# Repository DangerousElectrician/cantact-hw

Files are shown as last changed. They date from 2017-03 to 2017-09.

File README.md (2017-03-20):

I need a sensor node that sits on a CAN bus. This looks like a good place to start.

# CANtact Hardware

This repository contains the hardware design files for the CANtact tool. They 
can be opened and edited with [KiCad](http://www.kicad-pcb.org/).

A PDF of the schematic is available
[here](https://github.com/CANtact/cantact-hw/blob/master/cantact.pdf?raw=true).

## License

Hardware files released under the [Creative Commons Attribution-ShareAlike 4.0
International License](http://creativecommons.org/licenses/by-sa/4.0/) (CC BY-SA
4.0)

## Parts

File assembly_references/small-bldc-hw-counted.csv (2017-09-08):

Reference | Value | Footprint | Datasheet | MPN | MPN | count
R25 | 100 | Resistors_SMD:R_0201 |  | AC0201JR-07100RL
R26 | 100 | Resistors_SMD:R_0201 |  | AC0201JR-07100RL
R32 | 100 | Resistors_SMD:R_0201 |  | AC0201JR-07100RL
R33 | 100 | Resistors_SMD:R_0201 |  | AC0201JR-07100RL | AC0201JR-07100RL | 4
U2 | AZ1117C | TO_SOT_Packages_SMD:SOT89-3_Housing |  | AZ1117CR-3.3TRG1 | AZ1117CR-3.3TRG1 | 1
Q1 | BUK7K13-60E | hlib:SOT-1205 |  | BUK7K13-60EX
Q2 | BUK7K13-60E | hlib:SOT-1205 |  | BUK7K13-60EX
Q3 | BUK7K13-60E | hlib:SOT-1205 |  | BUK7K13-60EX | BUK7K13-60EX | 3
C20 | 22n | Capacitors_SMD:C_0603 |  | C0603C223K1RACTU | C0603C223K1RACTU | 1
C21 | 10u | Capacitors_SMD:C_0805 |  | C0805C106K8PACTU | C0805C106K8PACTU | 1
C22 | 2.2u | Capacitors_SMD:C_0603 |  | CC0603MRX5R7BB225 | CC0603MRX5R7BB225 | 1
C2 | 0.1u | Capacitors_SMD:C_0402 |  | CL05A104KP5NNNC
C9 | 0.1u | Capacitors_SMD:C_0402 |  | CL05A104KP5NNNC | CL05A104KP5NNNC | 2
C12 | 0.1u | Capacitors_SMD:C_0402 |  | CL05B104KO5NNNC
C14 | 0.1u | Capacitors_SMD:C_0402 |  | CL05B104KO5NNNC
C36 | 0.1u | Capacitors_SMD:C_0402 |  | CL05B104KO5NNNC
C37 | 0.1u | Capacitors_SMD:C_0402 |  | CL05B104KO5NNNC | CL05B104KO5NNNC | 4
C4 | 4.7u | Capacitors_SMD:C_0603 |  | CL10B475KQ8NQNC | CL10B475KQ8NQNC | 1
C23 | 22u | Capacitors_SMD:C_0805 |  | CL21A226MQQNNNE | CL21A226MQQNNNE | 1
C18 | 4.7u | Capacitors_SMD:C_0805 |  | CL21A475KAQNNNG | CL21A475KAQNNNG | 1
C24 | 0.1u | Capacitors_SMD:C_0805 |  | CL21B104KCFNNNE
C29 | 0.1u | Capacitors_SMD:C_0805 |  | CL21B104KCFNNNE | CL21B104KCFNNNE | 2
R27 | 1m | hlib:R_shunt_4_terminal_2512 |  | CRE2512-FZ-R001E-3
R34 | 1m | hlib:R_shunt_4_terminal_2512 |  | CRE2512-FZ-R001E-3 | CRE2512-FZ-R001E-3 | 2
U3 | DRV8301 | crf1:TSSOP-56-PP |  | DRV8301DCAR | DRV8301DCAR | 1
R18 | 15k | Resistors_SMD:R_0201 |  | ERJ-1GEJ153C | ERJ-1GEJ153C | 1
R16 | 18k | Resistors_SMD:R_0201 |  | ERJ-1GEJ183C | ERJ-1GEJ183C | 1
Y1 | 16MHz | hlib:Crystal_SMD_3225-4pin_3.2x2.5mm |  | FA-238 16.0000MB-K3 | FA-238 16.0000MB-K3 | 1
C1 | 10p | Capacitors_SMD:C_0201 |  | GRM0335C1H100JA01D
C5 | 10p | Capacitors_SMD:C_0201 |  | GRM0335C1H100JA01D | GRM0335C1H100JA01D | 2
C19 | 120p | Capacitors_SMD:C_0201 |  | GRM0335C1H121JA01D | GRM0335C1H121JA01D | 1
C32 | 2.2n | Capacitors_SMD:C_0201 |  | GRM033R71A222KA01D
C33 | 2.2n | Capacitors_SMD:C_0201 |  | GRM033R71A222KA01D
C34 | 2.2n | Capacitors_SMD:C_0201 |  | GRM033R71A222KA01D
C35 | 2.2n | Capacitors_SMD:C_0201 |  | GRM033R71A222KA01D | GRM033R71A222KA01D | 4
C15 | 4.7n | Capacitors_SMD:C_0201 |  | GRM033R71A472KA01D | GRM033R71A472KA01D | 1
C17 | 6.8n | Capacitors_SMD:C_0201 |  | GRM033R71A682KA01D | GRM033R71A682KA01D | 1
C11 | 1u | Capacitors_SMD:C_0402 |  | GRM155R61A105KE15D | GRM155R61A105KE15D | 1
C16 | 2.2u | Capacitors_SMD:C_0402 |  | GRM155R61A225KE95D | GRM155R61A225KE95D | 1
C26 | 0.1u | Capacitors_SMD:C_0402 |  | GRM155R61E104KA87D
C27 | 0.1u | Capacitors_SMD:C_0402 |  | GRM155R61E104KA87D
C28 | 0.1u | Capacitors_SMD:C_0402 |  | GRM155R61E104KA87D | GRM155R61E104KA87D | 3
C13 | 4.7u | Capacitors_SMD:C_0603 |  | GRM188R60J475KE19D
C8 | 4.7u | Capacitors_SMD:C_0603 |  | GRM188R60J475KE19D | GRM188R60J475KE19D | 2
C3 | 0.1u | Capacitors_SMD:C_0402 |  | GRM188R71C104KA01D
C6 | 0.1u | Capacitors_SMD:C_0402 |  | GRM188R71C104KA01D
C7 | 0.1u | Capacitors_SMD:C_0402 |  | GRM188R71C104KA01D | GRM188R71C104KA01D | 3
C10 | 10n | Capacitors_SMD:C_0402 |  | GRM188R71H103KA01D | GRM188R71H103KA01D | 1
C31 | 100u | Capacitors_SMD:C_1206 |  | GRM31CR60J107ME39L | GRM31CR60J107ME39L | 1
C25 | 4.7u | Capacitors_SMD:C_1210 |  | HMK325C7475KN-TE
C30 | 4.7u | Capacitors_SMD:C_1210 |  | HMK325C7475KN-TE
C38 | 4.7u | Capacitors_SMD:C_1210 |  | HMK325C7475KN-TE | HMK325C7475KN-TE | 3
D1 | LED-GREEN | LEDs:LED_0603 |  | LTST-C191KGKT | LTST-C191KGKT | 1
D2 | LED-RED | LEDs:LED_0603 |  | LTST-C191KRKT | LTST-C191KRKT | 1
U4 | MCP2562-E/SN | Housings_SOIC:SOIC-8_3.9x4.9mm_Pitch1.27mm |  | MCP2562FD-H/SN | MCP2562FD-H/SN | 1
R4 | 120 | Resistors_SMD:R_0201 |  | MCR03ERTF1200
R5 | 1k | Resistors_SMD:R_0201 |  | MCR03ERTF1200
R6 | 1k | Resistors_SMD:R_0201 |  | MCR03ERTF1200 | MCR03ERTF1200 | 3
R3 | 100k | Resistors_SMD:R_0201 |  | MCR03ERTF5100 | MCR03ERTF5100 | 1
JP1 | Boot Mode | Resistors_SMD:R_0603_HandSoldering |  | n/a
J3 | CONN_01X01 | hlib:SolderWirePad_single_SMD_5x3.5mm_holes |  | n/a
J4 | CONN_01X01 | hlib:SolderWirePad_single_SMD_5x3.5mm_holes |  | n/a
J5 | CONN_01X01 | hlib:SolderWirePad_single_SMD_5x3.5mm_holes |  | n/a
J8 | CONN_01X01 | hlib:SolderWirePad_single_SMD_5x3.5mm_holes |  | n/a
J9 | CONN_01X01 | hlib:SolderWirePad_single_SMD_5x3.5mm_holes |  | n/a
JP3 | Jumper_NC_Small | Resistors_SMD:R_0402 |  | n/a
JP2 | Jumper_NO_Small | Resistors_SMD:R_0402 |  | n/a
JP4 | Tie | hlib:NetTie-I_Connected_SMD |  | n/a | n/a
L1 | 22u | Inductors:Inductor_Taiyo-Yuden_NR-60xx |  | NR6045T220M | NR6045T220M | 1
D3 | D_Schottky | Diodes_SMD:D_SOD-123F |  | NRVTS260ESFT1G | NRVTS260ESFT1G | 1
R19 | 10k | Resistors_SMD:R_0201 |  | RC0201JR-0710KL
R20 | 10k | Resistors_SMD:R_0201 |  | RC0201JR-0710KL
R21 | 10k | Resistors_SMD:R_0201 |  | RC0201JR-0710KL
R9 | 10k | Resistors_SMD:R_0201 |  | RC0201JR-0710KL | RC0201JR-0710KL | 4
R22 | 220k | Resistors_SMD:R_0201 |  | RC0201JR-07220KL | RC0201JR-07220KL | 1
R7 | 2k | Resistors_SMD:R_0402 |  | RC0402JR-072KL
R8 | 2k | Resistors_SMD:R_0402 |  | RC0402JR-072KL | RC0402JR-072KL | 2
R23 | 2R2 | Resistors_SMD:R_0402 |  | RC0402JR-072R2L
R24 | 2R2 | Resistors_SMD:R_0402 |  | RC0402JR-072R2L
R28 | 2R2 | Resistors_SMD:R_0402 |  | RC0402JR-072R2L
R29 | 2R2 | Resistors_SMD:R_0402 |  | RC0402JR-072R2L
R30 | 2R2 | Resistors_SMD:R_0402 |  | RC0402JR-072R2L
R31 | 2R2 | Resistors_SMD:R_0402 |  | RC0402JR-072R2L | RC0402JR-072R2L | 6
R13 | 2k7 | Resistors_SMD:R_0201 |  | RC0603F272CS
R14 | 2k7 | Resistors_SMD:R_0201 |  | RC0603F272CS
R15 | 2k7 | Resistors_SMD:R_0201 |  | RC0603F272CS
R2 | 2k7 | Resistors_SMD:R_0201 |  | RC0603F272CS | RC0603F272CS | 4
R17 | 3k3 | Resistors_SMD:R_0201 |  | RC0603F332CS | RC0603F332CS | 1
R1 | 47k | Resistors_SMD:R_0603 |  | RC0603JR-074K7L
R10 | 47k | Resistors_SMD:R_0603 |  | RC0603JR-074K7L
R11 | 47k | Resistors_SMD:R_0603 |  | RC0603JR-074K7L
R12 | 47k | Resistors_SMD:R_0603 |  | RC0603JR-074K7L | RC0603JR-074K7L | 4
J2 | TEMP | Connectors_JST:JST_SH_SM02B-SRSS-TB_02x1.00mm_Angled |  | SM02B-SRSS-TB(LF)(SN) | SM02B-SRSS-TB(LF)(SN) | 1
J6 | CAN | Connectors_JST:JST_SH_SM04B-SRSS-TB_04x1.00mm_Angled |  | SM04B-SRSS-TB(LF)(SN)
J7 | I2C | Connectors_JST:JST_SH_SM04B-SRSS-TB_04x1.00mm_Angled |  | SM04B-SRSS-TB(LF)(SN) | SM04B-SRSS-TB(LF)(SN) | 2
P2 | SWD | Connectors_JST:JST_SH_SM05B-SRSS-TB_05x1.00mm_Angled |  | SM05B-SRSS-TB(LF)(SN) | SM05B-SRSS-TB(LF)(SN) | 1
J1 | More IO | Connectors_JST:JST_SH_SM12B-SRSS-TB_12x1.00mm_Angled |  | SM12B-SRSS-TB(LF)(SN) | SM12B-SRSS-TB(LF)(SN) | 1
U1 | STM32F042C6T6 | Housings_QFP:LQFP-48_7x7mm_Pitch0.5mm |  | STM32F042C6T6 | STM32F042C6T6 | 1

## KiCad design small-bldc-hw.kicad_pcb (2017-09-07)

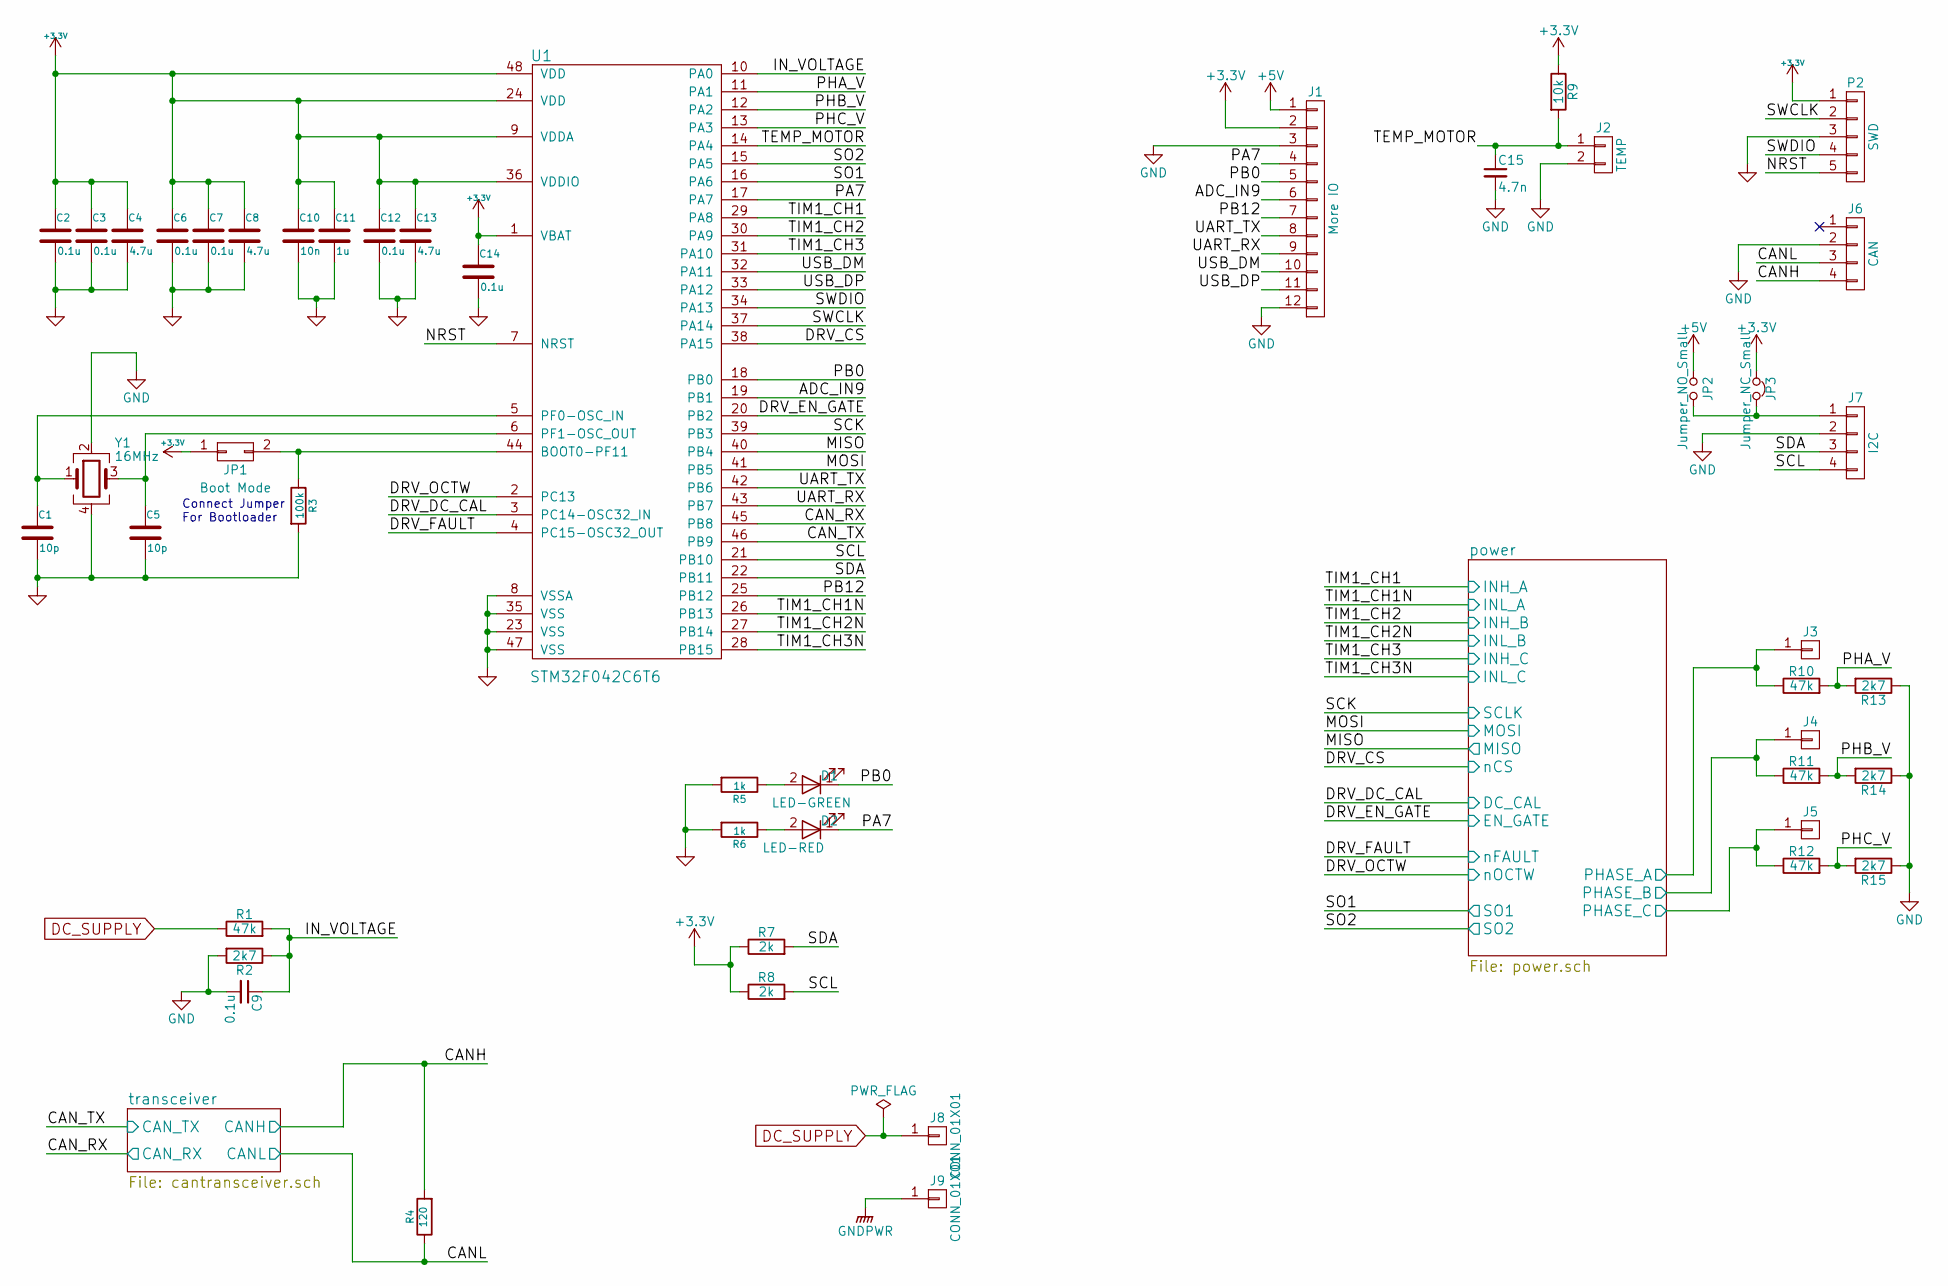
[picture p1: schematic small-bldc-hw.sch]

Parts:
C1, C5: 10p; C_0201; MPN GRM0335C1H100JA01D
C2, C9: 0.1u; C_0402; MPN CL05A104KP5NNNC
C3, C6, C7: 0.1u; C_0402; MPN GRM188R71C104KA01D
C4: 4.7u; C_0603; MPN CL10B475KQ8NQNC
C8, C13: 4.7u; C_0603; MPN GRM188R60J475KE19D
C10: 10n; C_0402; MPN GRM188R71H103KA01D
C11: 1u; C_0402; MPN GRM188R61E105KA12D
C12, C14: 0.1u; C_0402; MPN CL05B104KO5NNNC
C15: 4.7n; C_0201; MPN GRM033R71A472KA01D
D1: LED-GREEN; LED_0603; MPN LTST-C191KGKT
D2: LED-RED; LED_0603; MPN LTST-C191KRKT
J1: More IO; JST_SH_SM12B-SRSS-TB_12x1.00mm_Angled
J2: TEMP; JST_SH_SM02B-SRSS-TB_02x1.00mm_Angled
J3, J4, J5, J8, J9: CONN_01X01; SolderWirePad_single_SMD_5x3.5mm_holes
J6: CAN; JST_SH_SM04B-SRSS-TB_04x1.00mm_Angled
J7: I2C; JST_SH_SM04B-SRSS-TB_04x1.00mm_Angled
JP1: Boot Mode; R_0603_HandSoldering
JP2: Jumper_NO_Small; R_0402
JP3: Jumper_NC_Small; R_0402
P2: SWD; JST_SH_SM05B-SRSS-TB_05x1.00mm_Angled
R1, R10, R11, R12: 47k; R_0603
R2, R13, R14, R15: 2k7; R_0201
R3: 100k; R_0201; MPN MCR03ERTF5100
R4: 120; R_0201; MPN MCR03ERTF1200
R5, R6: 1k; R_0201; MPN MCR03ERTF1200
R7, R8: 2k; R_0402
R9: 10k; R_0201
U1: STM32F042C6T6; LQFP-48_7x7mm_Pitch0.5mm; MPN STM32F042C6T6
Y1: 16MHz; Crystal_SMD_3225-4pin_3.2x2.5mm; MPN FA-238 16.0000MB-K3

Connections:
+3V3: C2.1, C3.1, C4.1, C6.1, C7.1, C8.1, C10.1, C11.1, C12.1, C13.1, C14.1, J1.2, JP1.1, JP3.1, P2.1, R7.1, R8.1, R9.1, U1.1 (VBAT), U1.9 (VDDA), U1.24 (VDD), U1.36 (VDDIO), U1.48 (VDD); also elsewhere on the board
+5V: J1.1, JP2.1; also elsewhere on the board
/ADC_IN9: J1.6, U1.19 (PB1)
/CANH: J6.4, R4.2; also elsewhere on the board
/CANL: J6.3, R4.1; also elsewhere on the board
/CAN_RX: U1.45 (PB8); also elsewhere on the board
/CAN_TX: U1.46 (PB9); also elsewhere on the board
/DRV_CS: U1.38 (PA15); also elsewhere on the board
/DRV_DC_CAL: U1.3 (PC14-OSC32_IN); also elsewhere on the board
/DRV_EN_GATE: U1.20 (PB2); also elsewhere on the board
/DRV_FAULT: U1.4 (PC15-OSC32_OUT); also elsewhere on the board
/DRV_OCTW: U1.2 (PC13); also elsewhere on the board
/IN_VOLTAGE: C9.1, R1.2, R2.1, U1.10 (PA0)
/MISO: U1.40 (PB4); also elsewhere on the board
/MOSI: U1.41 (PB5); also elsewhere on the board
/NRST: P2.5, U1.7 (NRST)
/PA7: D2.1 (K), J1.4, U1.17 (PA7)
/PB0: D1.1 (K), J1.5, U1.18 (PB0)
/PB12: J1.7, U1.25 (PB12)
/PHA_V: R10.2, R13.2, U1.11 (PA1)
/PHB_V: R11.2, R14.2, U1.12 (PA2)
/PHC_V: R12.2, R15.2, U1.13 (PA3)
/SCK: U1.39 (PB3); also elsewhere on the board
/SCL: J7.4, R8.2, U1.21 (PB10)
/SDA: J7.3, R7.2, U1.22 (PB11)
/SO1: U1.16 (PA6); also elsewhere on the board
/SO2: U1.15 (PA5); also elsewhere on the board
/SWCLK: P2.2, U1.37 (PA14)
/SWDIO: P2.4, U1.34 (PA13)
/TEMP_MOTOR: C15.1, J2.1, R9.2, U1.14 (PA4)
/TIM1_CH1: U1.29 (PA8); also elsewhere on the board
/TIM1_CH1N: U1.26 (PB13); also elsewhere on the board
/TIM1_CH2: U1.30 (PA9); also elsewhere on the board
/TIM1_CH2N: U1.27 (PB14); also elsewhere on the board
/TIM1_CH3: U1.31 (PA10); also elsewhere on the board
/TIM1_CH3N: U1.28 (PB15); also elsewhere on the board
/UART_RX: J1.9, U1.43 (PB7)
/UART_TX: J1.8, U1.42 (PB6)
/USB_DM: J1.10, U1.32 (PA11)
/USB_DP: J1.11, U1.33 (PA12)
/power/PHASE_A: J3.1, R10.1; also elsewhere on the board
/power/PHASE_B: J4.1, R11.1; also elsewhere on the board
/power/PHASE_C: J5.1, R12.1; also elsewhere on the board
DC_SUPPLY: J8.1, R1.1; also elsewhere on the board
GND: C1.2, C2.2, C3.2, C4.2, C5.2, C6.2, C7.2, C8.2, C9.2, C10.2, C11.2, C12.2, C13.2, C14.2, C15.2, J1.3, J1.12, J2.2, J6.2, J7.2, P2.3, R2.2, R3.2, R5.2, R6.2, R13.1, R14.1, R15.1, U1.8 (VSSA), U1.23 (VSS), U1.35 (VSS), U1.47 (VSS), Y1.2, Y1.4; also elsewhere on the board
GNDPWR: J9.1; also elsewhere on the board
unnamed: C1.1, U1.5 (PF0-OSC_IN), Y1.1
unnamed: C5.1, U1.6 (PF1-OSC_OUT), Y1.3
unnamed: D1.2 (A), R5.1
unnamed: D2.2 (A), R6.1
unnamed: J7.1, JP2.2, JP3.2
unnamed: JP1.2, R3.1, U1.44 (BOOT0-PF11)

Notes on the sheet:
Connect Jumper For Bootloader

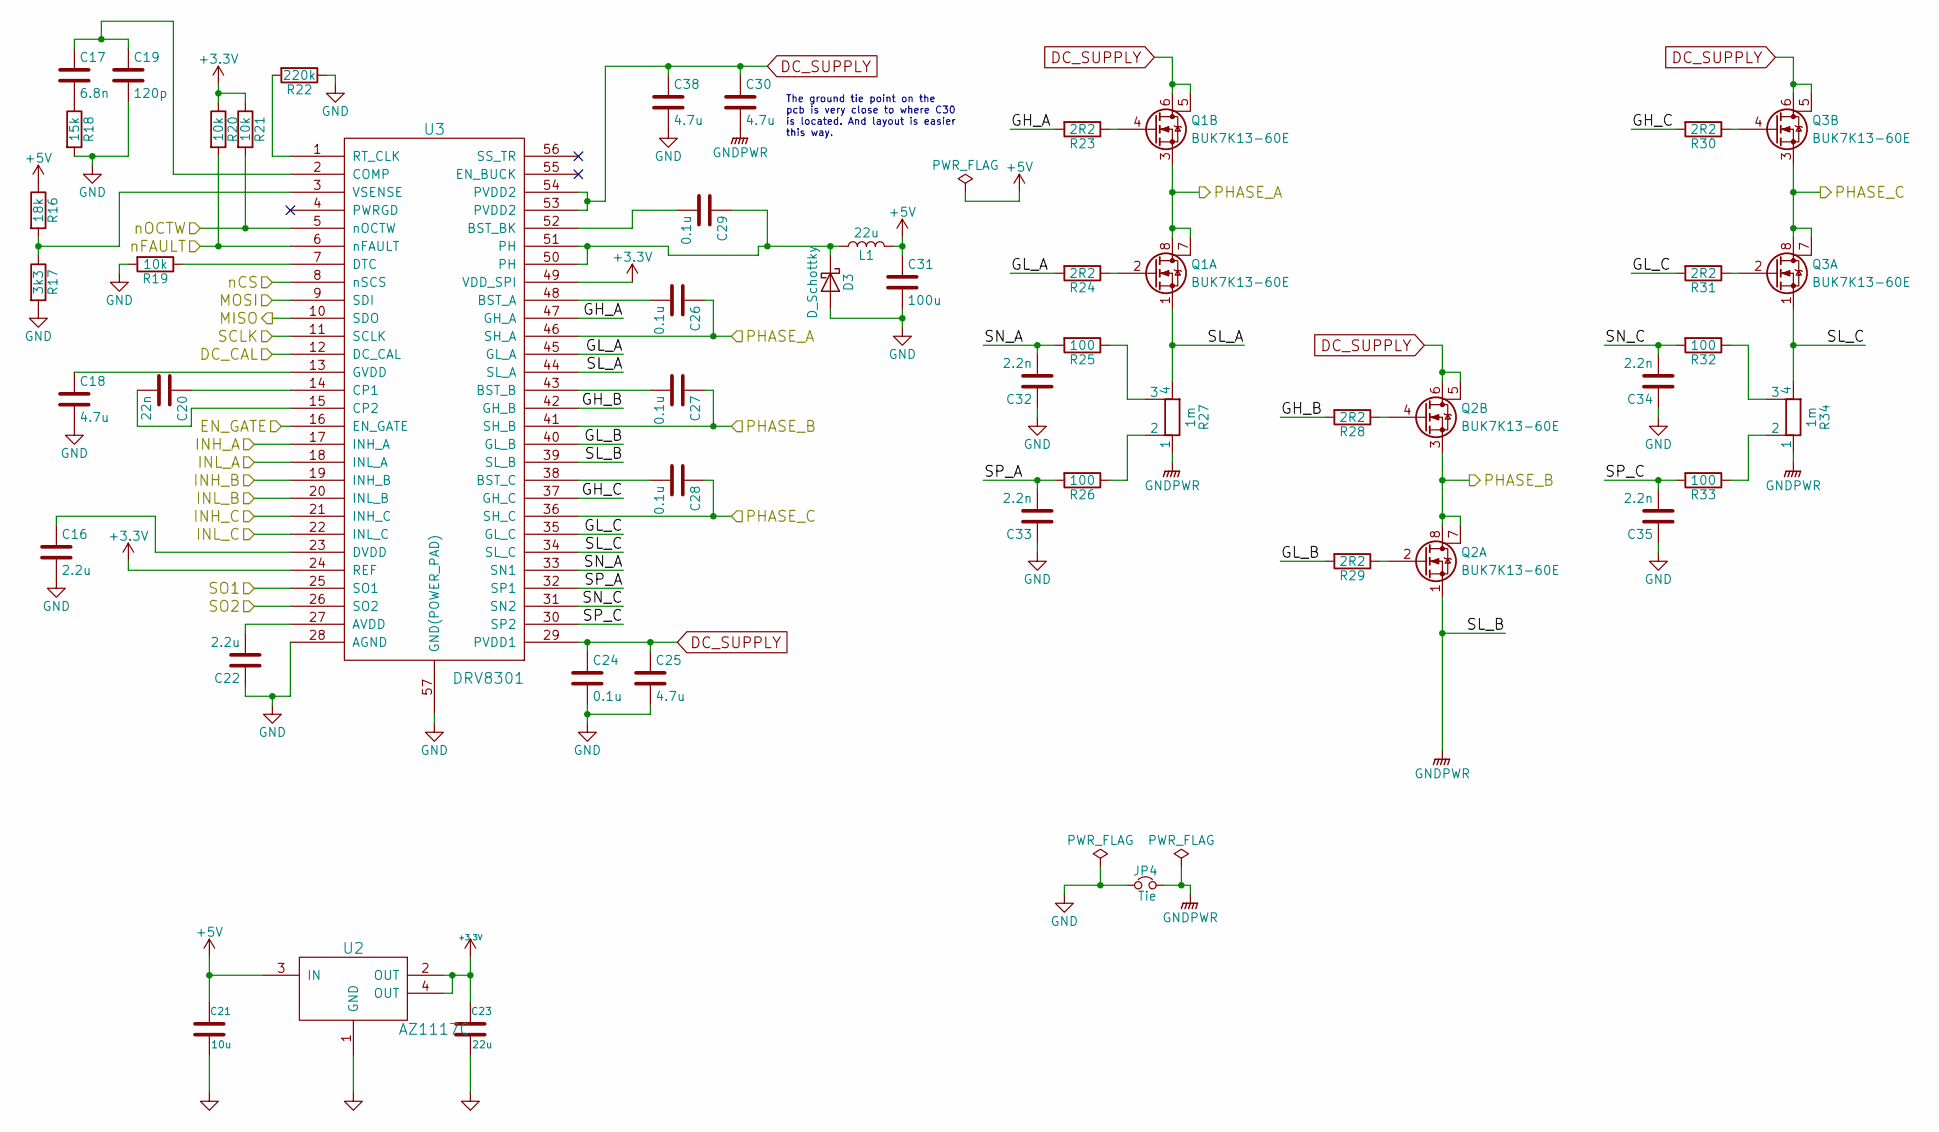
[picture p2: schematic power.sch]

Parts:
C16: 2.2u; C_0402; MPN GRM155R61A225KE95D
C17: 6.8n; C_0201; MPN GRM033R71A682KA01D
C18: 4.7u; C_0805; MPN CL21A475KAQNNNG
C19: 120p; C_0201; MPN GRM0335C1H121JA01D
C20: 22n; C_0603; MPN C0603C223K1RACTU
C21: 10u; C_0805; MPN C0805C106K8PACTU
C22: 2.2u; C_0603; MPN CC0603MRX5R7BB225
C23: 22u; C_0805; MPN CL21A226KQCLRNC
C24, C29: 0.1u; C_0805; MPN CL21B104KCFNNNE
C25, C30, C38: 4.7u; C_1210; MPN HMK325BJ475KM-PE
C26, C27, C28: 0.1u; C_0402; MPN GRM155R61E104KA87D
C31: 100u; C_1206; MPN GRM31CR60J107ME39L
C32: 2.2n; C_0201; MPN GRM033R71A222KA01D
C33, C34, C35: 2.2n; C_0201
D3: D_Schottky; D_SOD-123F; MPN NRVTS260ESFT1G
JP4: Tie; NetTie-I_Connected_SMD
L1: 22u; Inductor_Taiyo-Yuden_NR-60xx; MPN NR6045T220M
Q1, Q2, Q3: BUK7K13-60E; SOT-1205
R16: 18k; R_0201
R17: 3k3; R_0201
R18: 15k; R_0201
R19, R20, R21: 10k; R_0201
R22: 220k; R_0201
R23, R24, R28, R29, R30, R31: 2R2; R_0402
R25, R26, R32, R33: 100; R_0201
R27, R34: 1m; R_shunt_4_terminal_2512
U2: AZ1117C; SOT89-3_Housing; MPN AZ1117CR-3.3TRG1
U3: DRV8301; TSSOP-56-PP

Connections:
+3V3: C23.1, R20.1, R21.1, U2.2 (OUT), U2.4 (OUT), U3.24 (REF), U3.49 (VDD_SPI); also elsewhere on the board
+5V: C21.1, C31.1, L1.2, R16.1, U2.3 (IN); also elsewhere on the board
/DRV_CS: U3.8 (nSCS); also elsewhere on the board
/DRV_DC_CAL: U3.12 (DC_CAL); also elsewhere on the board
/DRV_EN_GATE: U3.16 (EN_GATE); also elsewhere on the board
/DRV_FAULT: R20.2, U3.6 (nFAULT); also elsewhere on the board
/DRV_OCTW: R21.2, U3.5 (nOCTW); also elsewhere on the board
/MISO: U3.10 (SDO); also elsewhere on the board
/MOSI: U3.9 (SDI); also elsewhere on the board
/SCK: U3.11 (SCLK); also elsewhere on the board
/SO1: U3.25 (SO1); also elsewhere on the board
/SO2: U3.26 (SO2); also elsewhere on the board
/TIM1_CH1: U3.17 (INH_A); also elsewhere on the board
/TIM1_CH1N: U3.18 (INL_A); also elsewhere on the board
/TIM1_CH2: U3.19 (INH_B); also elsewhere on the board
/TIM1_CH2N: U3.20 (INL_B); also elsewhere on the board
/TIM1_CH3: U3.21 (INH_C); also elsewhere on the board
/TIM1_CH3N: U3.22 (INL_C); also elsewhere on the board
/power/GH_A: R23.2, U3.47 (GH_A)
/power/GH_B: R28.2, U3.42 (GH_B)
/power/GH_C: R30.2, U3.37 (GH_C)
/power/GL_A: R24.2, U3.45 (GL_A)
/power/GL_B: R29.2, U3.40 (GL_B)
/power/GL_C: R31.2, U3.35 (GL_C)
/power/PHASE_A: C26.1, Q1.3 (S), Q1.7 (D), Q1.8 (D), U3.46 (SH_A); also elsewhere on the board
/power/PHASE_B: C27.1, Q2.3 (S), Q2.7 (D), Q2.8 (D), U3.41 (SH_B); also elsewhere on the board
/power/PHASE_C: C28.1, Q3.3 (S), Q3.7 (D), Q3.8 (D), U3.36 (SH_C); also elsewhere on the board
/power/SL_A: Q1.1 (S), R27.4, U3.44 (SL_A)
/power/SL_C: Q3.1 (S), R34.4, U3.34 (SL_C)
/power/SN_A: C32.2, R25.2, U3.33 (SN1)
/power/SN_C: C34.2, R32.2, U3.31 (SN2)
/power/SP_A: C33.2, R26.2, U3.32 (SP1)
/power/SP_C: C35.2, R33.2, U3.30 (SP2)
DC_SUPPLY: C24.1, C25.1, C30.1, C38.1, Q1.5 (D), Q1.6 (D), Q2.5 (D), Q2.6 (D), Q3.5 (D), Q3.6 (D), U3.29 (PVDD1), U3.53 (PVDD2), U3.54 (PVDD2); also elsewhere on the board
GND: C16.2, C18.2, C19.2, C21.2, C22.1, C23.2, C24.2, C25.2, C31.2, C32.1, C33.1, C34.1, C35.1, C38.2, D3.2 (A), JP4.1, R17.2, R18.2, R19.2, R22.1, U2.1 (GND), U3.28 (AGND), U3.57 (GND(POWER_PAD)); also elsewhere on the board
GNDPWR: C30.2, JP4.2, Q2.1 (S), R27.1, R34.1, U3.39 (SL_B); also elsewhere on the board
unnamed: C16.1, U3.23 (DVDD)
unnamed: C17.1, C19.1, U3.2 (COMP)
unnamed: C17.2, R18.1
unnamed: C18.1, U3.13 (GVDD)
unnamed: C20.1, U3.14 (CP1)
unnamed: C20.2, U3.15 (CP2)
unnamed: C22.2, U3.27 (AVDD)
unnamed: C26.2, U3.48 (BST_A)
unnamed: C27.2, U3.43 (BST_B)
unnamed: C28.2, U3.38 (BST_C)
unnamed: C29.1, D3.1 (K), L1.1, U3.50 (PH), U3.51 (PH)
unnamed: C29.2, U3.52 (BST_BK)
unnamed: Q1.2 (G), R24.1
unnamed: Q1.4 (G), R23.1
unnamed: Q2.2 (G), R29.1
unnamed: Q2.4 (G), R28.1
unnamed: Q3.2 (G), R31.1
unnamed: Q3.4 (G), R30.1
unnamed: R16.2, R17.1, U3.3 (VSENSE)
unnamed: R19.1, U3.7 (DTC)
unnamed: R22.2, U3.1 (RT_CLK)
unnamed: R25.1, R27.3
unnamed: R26.1, R27.2
unnamed: R32.1, R34.3
unnamed: R33.1, R34.2

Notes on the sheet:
The ground tie point on the pcb is very close to where C30 is located. And layout is easier this way.

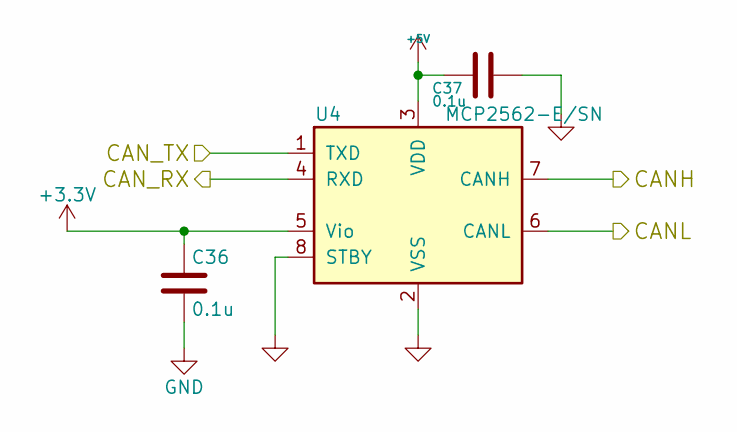
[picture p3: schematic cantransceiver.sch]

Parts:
C36: 0.1u; C_0402; MPN CL05B104KO5NNNC
C37: 0.1u; C_0402
U4: MCP2562-E/SN; SOIC-8_3.9x4.9mm_Pitch1.27mm

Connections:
+3V3: C36.1, U4.5 (Vio); also elsewhere on the board
+5V: C37.2, U4.3 (VDD); also elsewhere on the board
/CANH: U4.7 (CANH); also elsewhere on the board
/CANL: U4.6 (CANL); also elsewhere on the board
/CAN_RX: U4.4 (RXD); also elsewhere on the board
/CAN_TX: U4.1 (TXD); also elsewhere on the board
GND: C36.2, C37.1, U4.2 (VSS), U4.8 (STBY); also elsewhere on the board

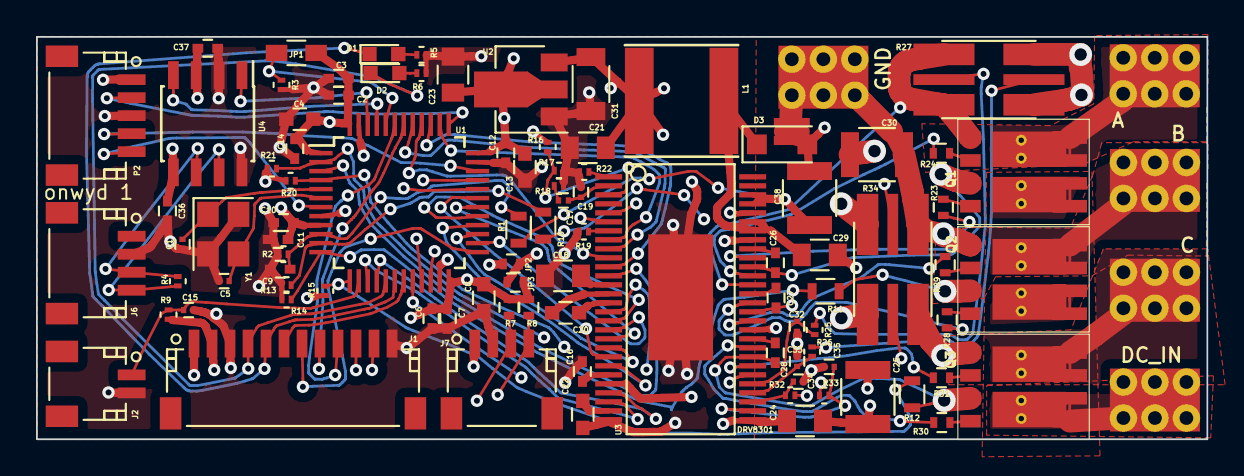
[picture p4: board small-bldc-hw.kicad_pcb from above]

Board: 4 copper layers, 65.0 x 22.4 mm, 98 parts (0 on the bottom side), 89 nets.

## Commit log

2017-03-20 read in the old schematic and reconnect all the changed symbols
    [cantact.sch]
2017-07-23 cleaning up
    [cantact-bom-v1_0.xls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]
2017-07-23 changes of some sort
    [cantransceiver.sch, microcontroller.sch, power.sch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]
2017-08-05 board design
    [small-bldc-hw.kicad_pcb]
2017-08-07 routed parts of the power section
    [small-bldc-hw.kicad_pcb]
2017-08-10 all the other stuff lying around but not committed yet, includes freerouting files
    [small-bldc-hw.csv, small-bldc-hw.dsn]
2017-08-10 rerouted a trace
    [small-bldc-hw.kicad_pcb]
2017-08-10 added additional ground via to drv8301 and fixed broken redundant trace
    [small-bldc-hw.kicad_pcb]
2017-08-10 fixed via drill size
    [small-bldc-hw.kicad_pcb]
2017-08-10 1 more layer to plane
    [small-bldc-hw.kicad_pcb]
2017-08-10 all planes done
    [small-bldc-hw.kicad_pcb]
2017-08-10 silkscreen references moved
    [small-bldc-hw.kicad_pcb]
2017-08-10 BOM stuff
    [small-bldc-hw.csv, small-bldc-hw.sch]
2017-08-11 update mpn
    [small-bldc-hw.csv]
2017-08-11 labelled the pads
    [small-bldc-hw.kicad_pcb]
2017-09-07 I think something relating to planes was changed
    [small-bldc-hw.dsn, small-bldc-hw.kicad_pcb]
2017-09-07 someone elses script to generate assembly drawings
2017-09-07 assembly drawing
2017-09-08 utility scripts for kicad
